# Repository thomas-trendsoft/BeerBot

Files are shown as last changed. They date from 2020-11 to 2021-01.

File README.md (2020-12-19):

# BeerBot

Erster Versuch eines simplen mobilen und teilautonomen Roboter. Basis-Aufgabe wird
"Hol ein Bier" oder anderen Gegenstandes von der Lager-Position bis zum anfordernden Benutzer.

Basis Aufgaben für die erste Version:

- Navigation / Mapping (Basis Orientierung)
- Object Detection (Bier erkennung)
- Steuerung der Aktuatoren zum Heben (Bier aufnehmen)

## Basis Aufbauplan

### Software

- TinySLAM als Navigation und Mapping Algorithmus
- YOLOvX as Object Detection Network mit eigenem Training für die Bierdose
- KiCAD für Schaltpläne
- FreeCAD für Bauteile und 3D Druck-Teile

### Hardware

Für die elektronische Steuerung und Wahrnehmung sind bisher folgende Sensoren und Bauteile vorgesehen:

- Raspberry Pi 3 (oder 4) als Basisboard
- HC-SR04 Distanzsensor für eine Feature und Hinderniserkennung
- 28BYJ-48 Schrittmotoren als Host für die Distanzmessung in unterschiedlichen Richtungen
- ULN2003 Schrittmotor Steuerung zum Ansprechen der Schrittmotoren
- MPU 6050 Gyroscope für die Berechnung von Winkeländerung und Beschleunigung
- 2 DC Motoren für den 2 Rad Antrieb  
- L298N Motortreiber für den Antrieb

Eine genaue Einkaufsliste soll später erstellt werden zum Nachbauen.

#### Hardware

##### PIN Belegung

Die PIN Nummer entspricht der GPIO Nummer bei der Raspberry Belegung.

- DC Motor 1
    - Pin0 = enable
    - Pin1 = in1
    - Pin7 = in2
- DC Motor 2
    - Pin9 = enable
    - Pin10 = in1
    - Pin11 = in2
- Servo Motor 1
    - Pin12 = PWM
- Servo Motor 2
    - Pin13 = PWM
- Schritt Motor
    - Pin22 = StepPin0
    - Pin23 = StepPin1
    - Pin24 = StepPin2
    - Pin25 = StepPin3
- HC-SR04 Distanzsensor
    - Pin17 = Echo
    - Pin18 = Trigger
- Taster1
    - Pin14 = IN
- Taster2
    - Pin15 = IN
- ODO Meter 1
    - Pin5 = IN
- ODO Meter 2
    - Pin6 = IN
- Gyroscope / MPU 6050
    - Pin2 = SDA (have to check I2C on Raspberry if not exact wrong)
    - Pin3 = SCL

##### Datenblätter/Papers

- TinySLAM: https://ieeexplore.ieee.org/document/5707402
- MPU6050 Basic Datasheet: https://invensense.tdk.com/wp-content/uploads/2015/02/MPU-6000-Datasheet1.pdf
- MPU6050 Register Datasheet: https://invensense.tdk.com/wp-content/uploads/2015/02/MPU-6000-Register-Map1.pdf

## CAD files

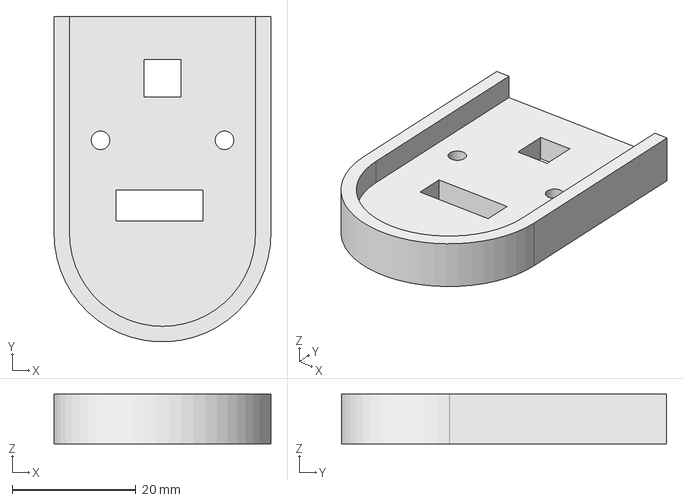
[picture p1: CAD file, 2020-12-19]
3DParts/Podest.FCStd
35.0 x 52.5 x 8.00 mm

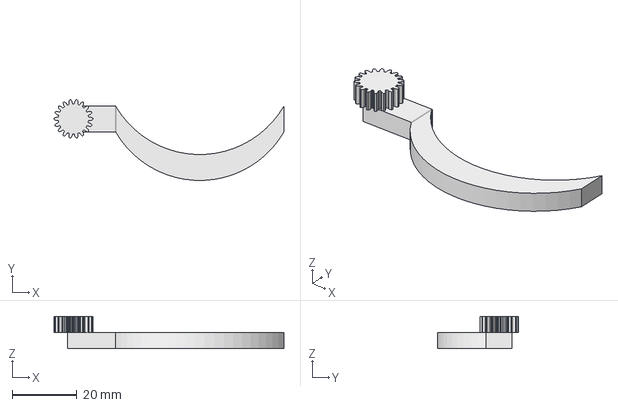
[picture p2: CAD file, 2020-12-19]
3DParts/Greifer.FCStd
71.0 x 24.9 x 10.0 mm

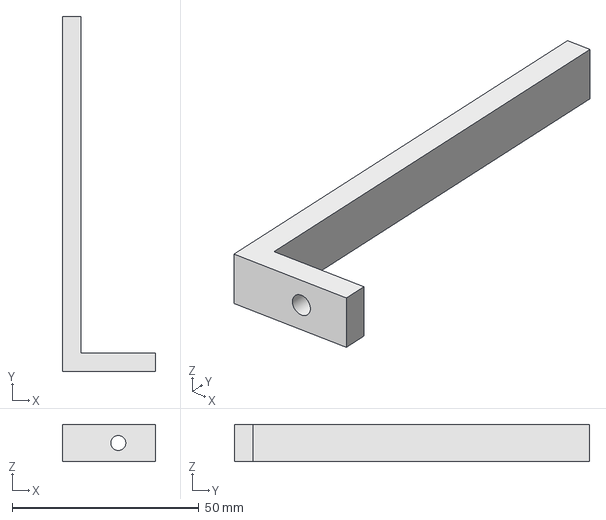
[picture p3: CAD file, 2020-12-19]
3DParts/CalibrationBlock.FCStd
25.0 x 95.0 x 10.0 mm

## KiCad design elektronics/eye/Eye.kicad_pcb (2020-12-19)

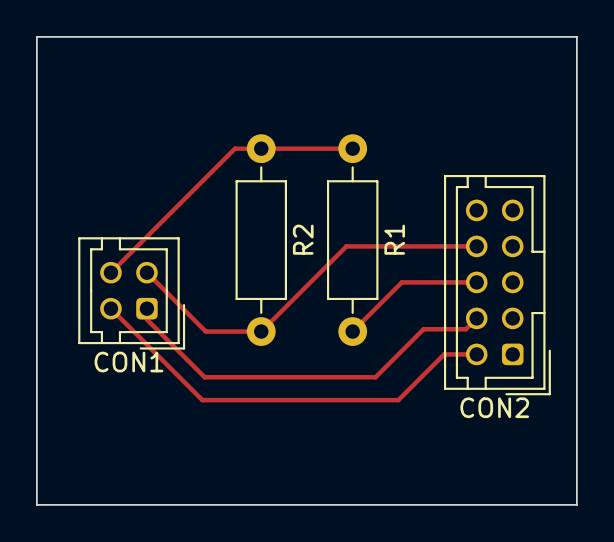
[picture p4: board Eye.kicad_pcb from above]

Board: 2 copper layers, 30.0 x 26.0 mm, 4 parts (0 on the bottom side), 5 nets.

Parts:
CON1: PI; JAE_LY20-4P-DT1_2x02_P2.00mm_Vertical
CON2: HC-SR04; JAE_LY20-10P-DT1_2x05_P2.00mm_Vertical
R1: R330; R_Axial_DIN0207_L6.3mm_D2.5mm_P10.16mm_Horizontal
R2: R10K; R_Axial_DIN0207_L6.3mm_D2.5mm_P10.16mm_Horizontal

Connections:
unnamed: CON1.a1, CON2.b2
unnamed: CON1.a2, CON2.b4, R2.2
unnamed: CON1.b1, CON2.b1
unnamed: CON1.b2, R1.1, R2.1
unnamed: CON2.b3, R1.2

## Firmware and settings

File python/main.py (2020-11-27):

import RPi.GPIO as GPIO
import DriveMotor
import Stepper
import Distance
import GyroSensor
import EyeScanner
import time
import math

#
# simple drive around first try
#
def driveAround():
    print("eye calibration: " + str(eye.calibrate()))
    print("remove calibration component")
    time.sleep(5)

    mindist = eye.simple_scan(20)
    print("min dist: " + str(mindist))

    driver  = DriveMotor.DriveMotor()

    # small drive around
    for i in range(0,4):
        print("next lane: " + str(i))

        # drive until no more space
        while mindist > 24.0:
            driver.forward()
            dval = mindist / 100.0
            if (dval < 0.3):
                dval = 0.3
            print("forward: " + str(dval))
            time.sleep(dval)
            driver.stop()
            time.sleep(0.1)
            mindist = eye.simple_scan(20)

        driver.backward()
        time.sleep(0.4)
        driver.stop()

        while mindist < 60.0:
            driver.turn_left()
            time.sleep(0.4)
            driver.stop()
            mindist = eye.simple_scan(20)


#
# test the gyro calibration
#
def testGyro():
    x_sum = 0
    y_sum = 0
    z_sum = 0
    for i in range(0,100):
        data = gyro.read_gyro_data()
        print(str(data))
        x_sum += data['x']
        y_sum += data['y']
        z_sum += data['z']
        time.sleep(0.1)

    df = 0.00763359

    print(str(x_sum) + "/" + str(y_sum) + "/" + str(z_sum))
    print(str(x_sum*df) + "/" + str(y_sum*df) + "/" + str(z_sum*df))

# main entry
if __name__ == "__main__":
    # setup gpio basic
    GPIO.setmode(GPIO.BCM)

    step = Stepper.Stepper()
    step.rotate(50,1)
    step.rotate(50,-1)

    GPIO.cleanup()

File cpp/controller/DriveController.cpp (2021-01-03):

#include <stdio.h>
#include <stdint.h>
#include <unistd.h>
#include <string.h>
#include <math.h>
#include <iostream>
#include <wiringPi.h>
#include "MPU6050_6Axis_MotionApps20.h"
#include "DriveController.h"

int stop_pos_thread = 0;

// TODO check interrupt controlled
void* update_position_thread(void* ctrlptr) {
	DriveController* ctrl = (DriveController*)ctrlptr;

	while (!stop_pos_thread) {
		ctrl->updatePosition();
		delay(10);
	}

	pthread_exit(NULL);
}

//
// default constructor
//
DriveController::DriveController() {
  this->dmpReady      = false;
  this->pos.x         = 0.0;
  this->pos.y         = 0.0;
  this->pos.theta     = 0.0;
  this->fstop         = 0;
  this->eye           = NULL;
  this->last_odo_diff = 0;
	this->mdir          = -1;
}

//
// hardware init routine
//
void DriveController::initialize(EyeScanner* eye) {

  // save eye scanner ref
  this->eye = eye;

  // initialize device
  printf("Initializing MPU6050 devices...\n");
  mpu.initialize();

  // verify connection
  printf("Testing gyro device connections...\n");
  printf(mpu.testConnection() ? "MPU6050 connection successful\n" : "MPU6050 connection failed\n");

  // load and configure the DMP
  printf("Initializing DMP...\n");
  mpuStatus = mpu.dmpInitialize();

  // make sure it worked (returns 0 if so)
  if (mpuStatus == 0) {
      // turn on the DMP, now that it's ready
      printf("Enabling DMP...\n");
      mpu.setDMPEnabled(true);
      mpuIntStatus = mpu.getIntStatus();
      printf("DMP ready!\n");
      dmpReady = true;
      packetSize = mpu.dmpGetFIFOPacketSize();

      delay(10);
      this->updatePosition();
  } else {
      // ERROR!
      // 1 = initial memory load failed
      // 2 = DMP configuration updates failed
      // (if it's going to break, usually the code will be 1)
      printf("DMP Initialization failed (code %d)\n", mpuStatus);
  }

  // start position thread
  pthread_create(&this->posThread,NULL,&update_position_thread,(void*)this);

}

// set current position to 0,0
void DriveController::resetPosition() {
	pos.x = 0.0;
	pos.y = 0.0;
}

//
// show current position information
//
bb_position DriveController::getStatus() {
  return pos;
}

void DriveController::getPosition(bb_position* p) {
	p->x     = pos.x;
	p->y     = pos.y;
	p->theta = pos.theta;
}

void DriveController::updatePosition() {
  // orientation/motion vars
  Quaternion  q;           // [w, x, y, z]         quaternion container
  VectorFloat gravity;    // [x, y, z]            gravity vector
  float       ypr[3];           // [yaw, pitch, roll]   yaw/pitch/roll container and gravity vector

  int fifoCount = mpu.getFIFOCount();

  if (fifoCount == 1024) {
      // reset so we can continue cleanly
      mpu.resetFIFO();
      printf("FIFO overflow!\n");

  // otherwise, check for DMP data ready interrupt (this should happen frequently)
  } else if (fifoCount >= 42) {
      // work update position steps from fifo buffer
      while (fifoCount >= 42) {
        // read a packet from FIFO
        mpu.getFIFOBytes(fifoBuffer, packetSize);

        // display Euler angles in degrees
        mpu.dmpGetQuaternion(&q, fifoBuffer);
        mpu.dmpGetGravity(&gravity, &q);
        mpu.dmpGetYawPitchRoll(ypr, &q, &gravity);

				// update looking direction
				this->pos.theta = ypr[0];

				// get odo position
				int pos   = std::min(odo_left.count(),odo_right.count());
				int delta = pos - this->last_odo_diff;

				this->last_odo_diff = pos;

				if (delta > 0) {
					if (this->mdir == M_FORWARD) {
						// calculate direction factors
		        double c = cos(ypr[0]);
		        double s = sin(ypr[0]);

						double dx = c * delta * ODO_TICK_LEN;
		        double dy = s * delta * ODO_TICK_LEN;

						this->pos.x += dx;
						this->pos.y += dy;
					}
				}

        fifoCount = mpu.getFIFOCount();
      }
  }
}

void DriveController::balance(double dir) {
	system_clock::time_point tm = system_clock::now();

  double Kp = 1.4;
	double Ki = 0.0;
	double Kd = 2.8;

  double mp = this->pos.theta * 180.0 / M_PI;
  double dv = dir * 180.0 / M_PI;

  double err  = dv - mp;

	if (std::abs(err) > 180.0) {
	  if (err > 0) {
		  err = err - 360.0;
	  } else {
		  err = 360.0 + err;
	  }
  }

	double derr = err - last_dir_err;
	last_dir_err = err;
	double dt = (tm - this->last_dir_update).count();
	this->balance_integral = this->balance_integral + (err * dt);

	double kpu = Kp * err;
	double kiu = Ki * this->balance_integral;
	double kdu = Kd * derr;

	int update = std::abs((int)(kpu + kiu + kdu));

	// not maximize diff to avoid drifting
	if (update > BAL_MAX_DIFF) update = BAL_MAX_DIFF;

  if (update != 0) {
		if (err < 0) {
	  	motors.setMotorLeftValue(BAL_REF_VAL - update);
	  	motors.setMotorRightValue(BAL_REF_VAL + update);
  	} else if (err > 0) {
	  	motors.setMotorLeftValue(BAL_REF_VAL + update);
	  	motors.setMotorRightValue(BAL_REF_VAL - update);
		}
  }

}

//
// drive forward for "dist" steps
//
void DriveController::forward(int dist) {
  fstop = 0;
  odo_left.reset();
  odo_right.reset();

	// save current direction
  double direction = this->pos.theta;

	// init PID controller
	this->last_dir_err     = 0.0;
	this->last_dir_update  = system_clock::now();
	this->balance_integral = 0.0;

	// activate position updates
	this->last_odo_diff = 0;
	this->mdir = M_FORWARD;

  double maxdist = this->eye->distance();

	// start drive
	motors.forward();

	// drive until stop signal / distance reached / or occupied
  while (!fstop && maxdist > 24.0 && odo_left.count() < dist && odo_right.count() < dist) {
    delay(40);
    this->balance(direction);
    maxdist = this->eye->distance();
  }

	motors.stop();
	delay(200);


}

//
// drive backward for "dist" steps
//
void DriveController::backward(int dist) {
  fstop = 0;
  odo_left.reset();
  odo_right.reset();

	this->mdir = M_BACKWARD;

  motors.backward();
  while (!fstop && odo_left.count() < dist && odo_right.count() < dist) {
    delay(2);
  }
  motors.stop();
}

//
// turn left for given odo meter steps
//
void DriveController::turn_left(int steps) {
  fstop = 0;
  odo_left.reset();
  odo_right.reset();

	this->mdir = M_LEFT;

  motors.turn_left();
  while (!fstop && odo_left.count() < steps && odo_right.count() < steps) {
    delay(2);
  }
  motors.stop();
}

//
// turn right for given odo meter steps
//
void DriveController::turn_right(int steps) {
  fstop = 0;
  odo_left.reset();
  odo_right.reset();

	this->mdir = M_RIGHT;

  motors.turn_right();
  while (!fstop && odo_left.count() < steps && odo_right.count() < steps) {
    delay(2);
  }
  motors.stop();
}

void DriveController::stopMove() {
  fstop = 1;
  motors.stop();
}

void DriveController::shutdown() {
	stop_pos_thread = 1;
	delay(20);
	mpu.reset();
}

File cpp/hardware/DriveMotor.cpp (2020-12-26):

#include <wiringPi.h>
#include <softPwm.h>
#include "DriveMotor.h"

//
// default constructor
//
DriveMotor::DriveMotor() {

  // initialize gpio pins
  pinMode(DCM_IN1,OUTPUT);
  pinMode(DCM_IN2,OUTPUT);
  pinMode(DCM_IN3,OUTPUT);
  pinMode(DCM_IN4,OUTPUT);
  pinMode(DCM_EN2,OUTPUT);
  pinMode(DCM_EN1,OUTPUT);

  // init pin values
  digitalWrite(DCM_IN1,LOW);
  digitalWrite(DCM_IN2,LOW);
  digitalWrite(DCM_IN3,LOW);
  digitalWrite(DCM_IN4,LOW);

  // init pwm pins
  softPwmCreate (DCM_EN1, 0, 100);
  softPwmCreate (DCM_EN2, 0, 100);

}

// update motor output value for motor 1
void DriveMotor::setMotorLeftValue(int val) {
  this->dcm1val = val;
  softPwmWrite (DCM_EN1, this->dcm1val);
}

// update motor output value for motor 2
void DriveMotor::setMotorRightValue(int val) {
  this->dcm2val = val;
  softPwmWrite (DCM_EN2, this->dcm2val);
}

// motor output value for motor 1
int DriveMotor::getMotorLeftValue() {
  return this->dcm1val;
}

// motor output value for motor 2
int DriveMotor::getMotorRightValue() {
  return this->dcm2val;
}


// backward driving
void DriveMotor::backward() {

  softPwmWrite (DCM_EN1, this->dcm1val);
  softPwmWrite (DCM_EN2, this->dcm2val);

  digitalWrite(DCM_IN1,LOW);
  digitalWrite(DCM_IN2,HIGH);
  digitalWrite(DCM_IN3,LOW);
  digitalWrite(DCM_IN4,HIGH);

}


//
// forward driving
//
void DriveMotor::forward() {
  softPwmWrite (DCM_EN1, this->dcm1val);
  softPwmWrite (DCM_EN2, this->dcm2val);

  digitalWrite(DCM_IN1,HIGH);
  digitalWrite(DCM_IN2,LOW);
  digitalWrite(DCM_IN3,HIGH);
  digitalWrite(DCM_IN4,LOW);
}

// turn left
void DriveMotor::turn_left() {
  softPwmWrite (DCM_EN1, this->dcm1val);
  softPwmWrite (DCM_EN2, this->dcm2val);

  digitalWrite(DCM_IN1,LOW);
  digitalWrite(DCM_IN2,HIGH);
  digitalWrite(DCM_IN3,HIGH);
  digitalWrite(DCM_IN4,LOW);
}

// turn right
void DriveMotor::turn_right() {
  softPwmWrite (DCM_EN1, this->dcm1val);
  softPwmWrite (DCM_EN2, this->dcm2val);

  digitalWrite(DCM_IN1,HIGH);
  digitalWrite(DCM_IN2,LOW);
  digitalWrite(DCM_IN3,LOW);
  digitalWrite(DCM_IN4,HIGH);
}

//
// stop motor output
//
void DriveMotor::stop() {
  softPwmWrite (DCM_EN1, 0);
  softPwmWrite (DCM_EN2, 0);

  this->dcm1val = 34;
  this->dcm2val = 34;

  digitalWrite(DCM_IN1,LOW);
  digitalWrite(DCM_IN2,LOW);
  digitalWrite(DCM_IN3,LOW);
  digitalWrite(DCM_IN4,LOW);
}

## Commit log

2020-11-24 cpp project steps / simple python calibration
2020-11-24 drive motor implementation / driveAround test
2020-11-27 stepper tested / distance tested / eyescanner tested
2020-11-27 param optimized / i2c dev param
2020-12-16 fix client accept socket thread / send client handler msg / client ui refactoring
2020-12-18 base network handling / ui pause button and first info pull test
2020-12-18 commands for move button
2020-12-19 add electronics and 3d part first steps
    [CalibrationBlock.FCStd, Eye.kicad_pcb, Eye.sch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]
2020-12-19 first little remote control by client / new podest design / pcb with drill holes
    [Eye.kicad_pcb, Podest.FCStd]
2020-12-26 protocol for position pull / very simple pid controller for forward driving
2020-12-27 more dynamic pid control
2020-12-28 client long run task / pid tuning / ui position units
2020-12-28 eye scan as array for tinyslam / client task thread isolation fix / start mapping function
    [DriveController.cpp, Eyescanner.cpp]
2021-01-03 c++ / threads / map widget / logging
